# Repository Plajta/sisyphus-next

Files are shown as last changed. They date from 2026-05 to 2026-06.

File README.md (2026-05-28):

# Sisyphus
Sisyphus is an open-source, customizable soundboard. It's built to help folks who need assistive tech, but it's also great if you just want a cool device that makes noises when you hit buttons.

This repo contains everything you need to build one: the PCB designs, the 3D-printable case, and the firmware that makes it all work, with a construction manual in the works.

If you're looking for the web configurator to manage your sounds, check out [Lithos](https://lithos.plajta.eu/) (source code [here](https://github.com/Plajta/lithos)).

## Key features
With **RP2040** as it's beating heart and a nice crisp **I2S DAC**, it can even do CD quality audio (if you're into that kinda thing).
All the audio is kept in the device's **internal flash** held together by LittleFS making it resilient.

Made with our custom **[Eternity](https://github.com/Plajta/eternity) bootloader** it can be updated even from a browser. 

A built in **color sensor** makes it easy to swap your sound sets by just swapping in a piece of paper and **magnets** make it all feel like magic.
Built in a sturdy, slim, and light **3D-printed body**, held together by friction and screws for easy repairs. (Construction manual coming soon™)

## Directory structure
- [3D/](3D/) - The mechanical parts. Contains the FreeCAD project and [STLs](3D/STLs) ready for printing.
- [PCBs/](PCBs/) - KiCAD projects for the [mainboard](PCBs/sisyphus) and our own slim [RGB sensor module](PCBs/rgb_sensor).
- [src/](src/) - The firmware. It handles everything from the USB stack and keyboard matrix to the audio playback. Check its [README](src/README.md) for more details.

## Licensing
We take open-source seriously, so each part of the project has its own license to keep it fair:
- **3D & PCBs:** [CC-BY-SA](https://creativecommons.org/licenses/by-sa/4.0/)
- **Firmware (src):** [GPLv3](https://www.gnu.org/licenses/gpl-3.0.html)

That means you're free to use, modify, and even sell this—as long as you share your changes back with the community under the same terms.

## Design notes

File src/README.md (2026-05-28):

# Sisyphus Firmware
An RP2040 firmware built primarily for SisyFOSS boards. It includes a filesystem, color processing, a USB stack with a custom protocol, and a keyboard driver!

While this firmware is designed for custom boards, it can still run on a standard Raspberry Pi Pico, though the experience may be limited.

A custom linker script is used during the build process to reserve a dedicated section of the flash JUST for the LittleFS filesystem. This ensures that data is preserved when upgrading the firmware.

## Repository Structure
- [Audio](audio/) - Manages audio playback and loading - built from [RPi's code](https://github.com/raspberrypi/pico-playground/blob/master/audio/sine_wave/sine_wave.c)
- [Battery management](battery/) - Drivers for BMS chips
- [Boards](boards/) - Headers for supported boards
- [Color](color/) - Drivers for color sensors, color management, and color LUT
- [Eternity](https://github.com/Plajta/eternity) - Submodule for our custom 3rd-stage bootloader for the RP2040
- [Keyboard](keyboard/) - Drivers for keyboard controller ICs
- [LittleFS](https://github.com/littlefs-project/littlefs) - Submodule for an amazing and small fail-safe filesystem for microcontrollers.
- [Protocol](protocol/) - A custom protocol for file management, diagnostics, and configuration
- [USB](usb/) - TinyUSB configuration and descriptors
- [Util](util/) - Misc stuff, setup for LittleFS for the RP2040, ARGB LED color indicator

## Installation
To build the firmware from source, refer to the [Building](#building) section.

GitHub Actions automatically build the latest commits in three versions:
1. **Pico**: Standard firmware for the Raspberry Pi Pico (primarily for testing).
2. **Pico + Eternity**: Firmware for the Pico including the Eternity bootloader (also for testing).
3. **SisyFOSS**: Firmware for the SisyFOSS β board, including Eternity.

To install the standard Pico firmware, flash `sisyphus.uf2`.

Builds that include Eternity can be flashed in two ways:
1. Flash `combined.uf2` using the standard method.
2. If Eternity is already installed on the board, flash the `sisyphus.bin` file using the [web interface](https://lithos.plajta.eu/) (still WIP) or the [Eternity flasher](https://github.com/Plajta/eternity/blob/main/protocol/flasher.py).

## Usage
The primary way to interact with the firmware is through the [web interface](https://lithos.plajta.eu/) ([code](https://github.com/Plajta/lithos)).

If you want to take a look inside or just like to do stuff yourself, look inside in the [Protocol](protocol/) directory for its README and a bunch of interesting scripts.

To manually insert audio files, you also need to understand how the device chooses which file to play.
When a button is pressed, the firmware tries to play a file from its filesystem based on the following name template:
```
<color>_<row>_<column>.wav
```
- `<color>` - An ASCII letter mapped from the color LUT. See the [color](color/) directory for details.
- `<row>` and `<column>` - The coordinates of the button in the keyboard matrix (starting from 0).

### Initial Device Setup
When setting up a new or reset device with an empty filesystem, a few files must be prepared.

#### Color Lookup Table (LUT)
The LUT maps sensor readings to specific color codes and LED displays. To generate a stable LUT, run the [calibrator.py](protocol/calibrator.py) script with the device connected. The script will guide you through the calibration process using color samples, make sure to prepare those from the printer you plan on using in all the supported colors.

Currently supported colors:
- Red
- Green
- Blue
- Cyan
- Magenta
- Yellow
- White

For more information on color detection, see to the [color](color/) directory.

#### Volume Feedback Sample
An optional but recommended file, `volume_sample.wav`, provides audible feedback when the user adjusts the device volume. It should be a short chime representative of the volume of your typical audio samples.

The easiest way to prepare and upload this chime is using the [convert.py](protocol/convert.py) script:
```bash
python protocol/convert.py <path_to_audio_sample> volume_sample.wav
```
This script automatically converts the sample to 16-bit PCM at 22 kHz and uploads it to the device.

Alternatively, you can use a 3rd-party tool like Audacity to prepare the file and upload it via the [web interface](https://lithos.plajta.eu/) or the [shell.py](protocol/shell.py) script.

## Building
Building was only tested on Linux, it might work elsewhere but only to a limited extent.

If you are new to `pico-sdk` development, refer to the official Raspberry Pi documentation ([Getting Started](https://datasheets.raspberrypi.com/pico/getting-started-with-pico.pdf), [SDK Quick Start](https://www.raspberrypi.com/documentation/microcontrollers/c_sdk.html#quick-start-your-own-project)) for toolchain installation instructions.

1. **Update Submodules**: Ensure all submodules (Eternity and LittleFS) are cloned and up to date.
   ```bash
   git submodule update --init --recursive
   ```

2. **Create Build Directory**:
   ```bash
   mkdir build
   cd build
   ```

3. **Configure and Build**:
   Since the firmware is optimized for SisyFOSS boards, you should specify the board type. To include Eternity, use the `USE_ETERNITY` flag.
   ```bash
   cmake -DPICO_BOARD=plajta_sisyfoss_beta -DUSE_ETERNITY=ON ..
   make
   ```
   This should produce a bunch of binaries, but the ones you are interested in are either `sisyphus.uf2` (standard) or `combined.uf2` and `sisyphus.bin` (for Eternity-based systems). See the [Installation](#installation) section for deployment details.

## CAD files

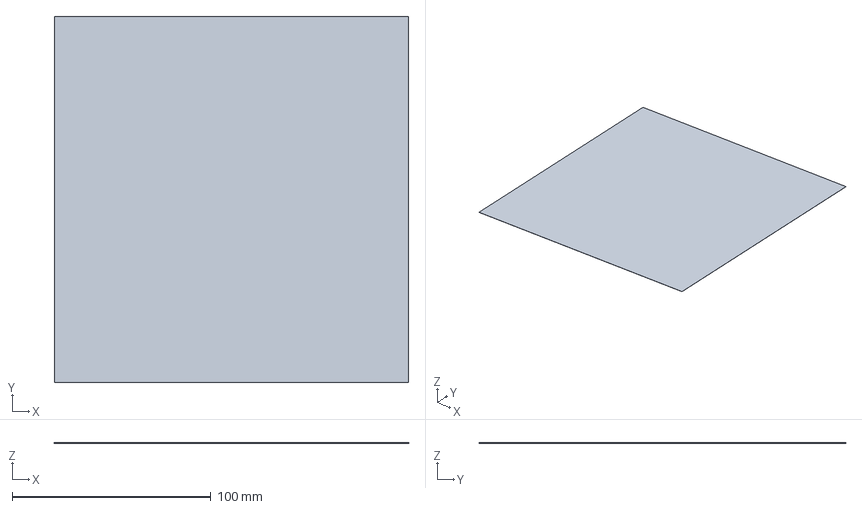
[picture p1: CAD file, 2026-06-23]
3D/Sisyphus.FCStd
178.0 x 184.0 x 0.1 mm

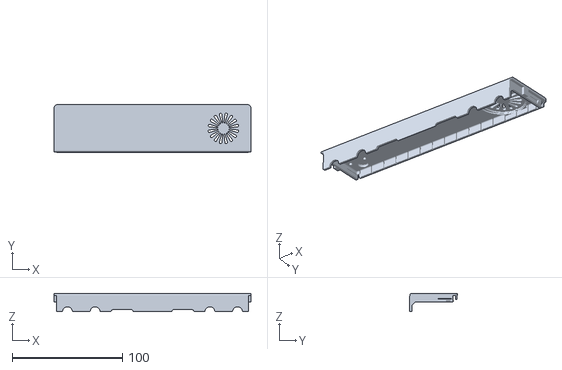
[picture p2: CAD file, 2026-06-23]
3D/STLs/TopCover-topcover.stl
178.4 x 43.4 x 16.6

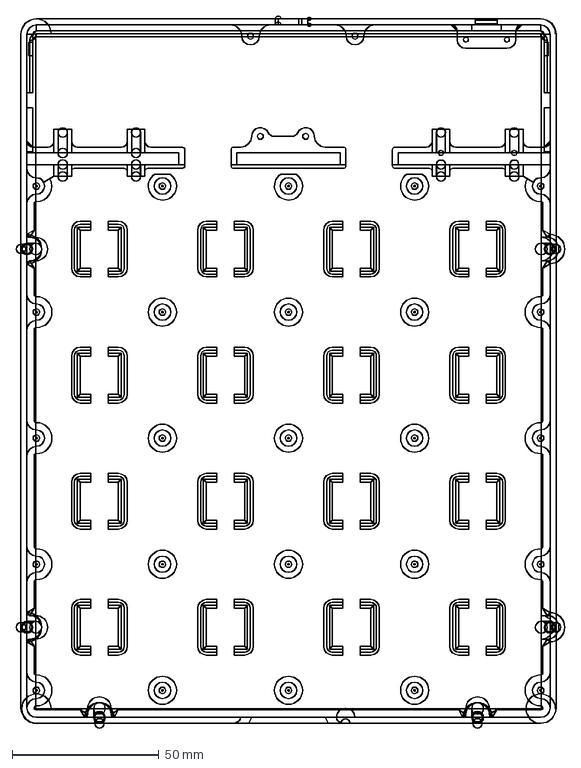
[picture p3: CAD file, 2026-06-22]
3D/STLs/Bottom-botom.dxf
187.0 x 242.8 mm

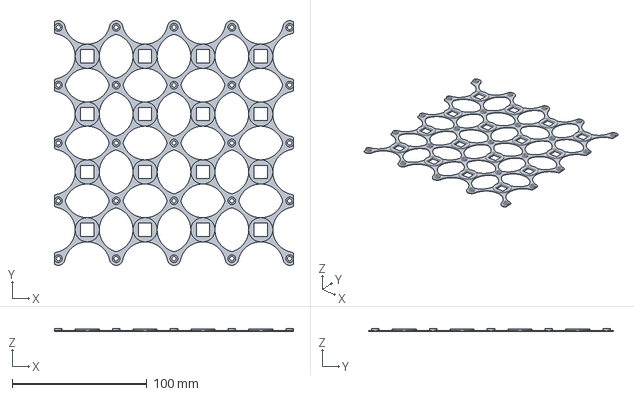
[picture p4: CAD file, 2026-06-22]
3D/Spring.FCStd
177.7 x 182.0 x 2.50 mm

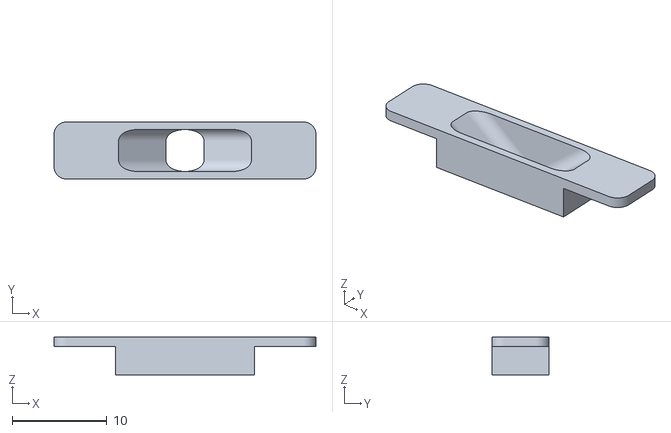
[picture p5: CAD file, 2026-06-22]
3D/STLs/Top-sensorcover.stl
27.6 x 6.00 x 4.00

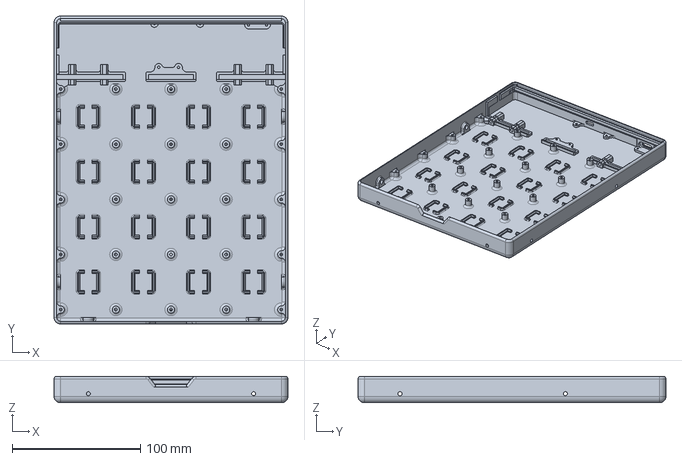
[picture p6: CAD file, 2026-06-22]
3D/Bottom.FCStd
182.5 x 240.2 x 20.6 mm

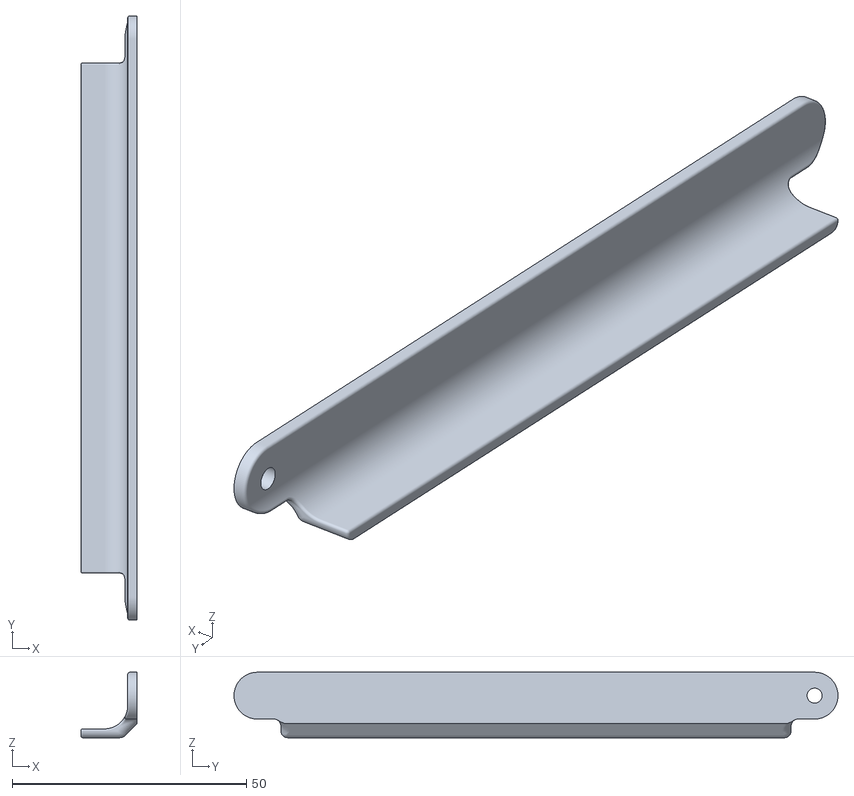
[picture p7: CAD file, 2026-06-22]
3D/STLs/sisyphus-leg.stl
12.0 x 129.0 x 14.0

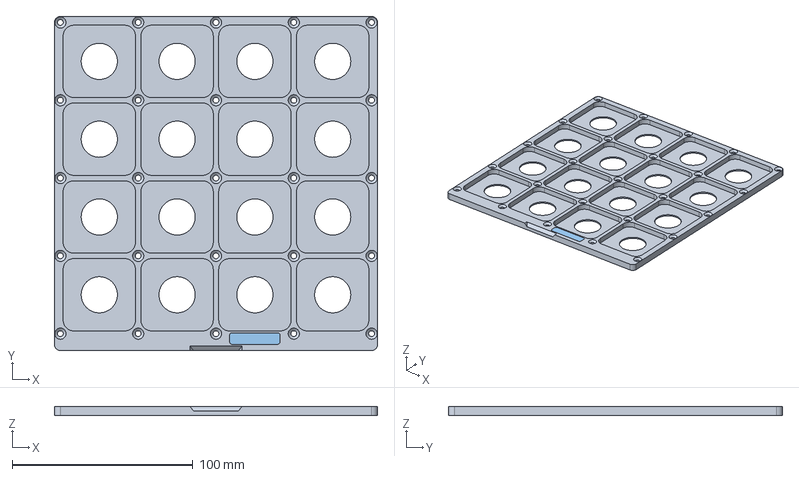
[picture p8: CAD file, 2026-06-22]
3D/Top.FCStd
178.6 x 184.6 x 5.00 mm
top
sensorcover
sensorglass

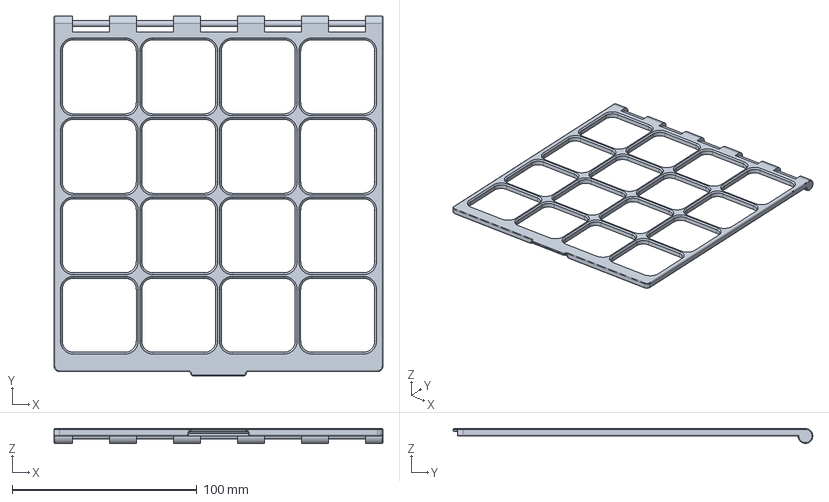
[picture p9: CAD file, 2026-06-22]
3D/Lid.FCStd
178.0 x 194.5 x 8.00 mm

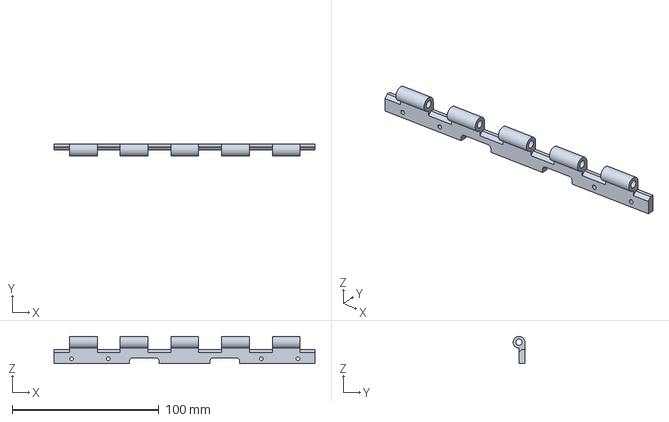
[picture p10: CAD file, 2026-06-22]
3D/Hinge.FCStd
178.0 x 8.00 x 18.6 mm

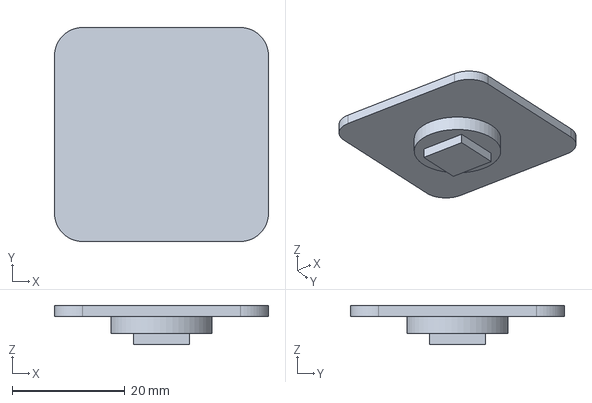
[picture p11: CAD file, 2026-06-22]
3D/KeyCap.FCStd
38.0 x 38.0 x 7.00 mm

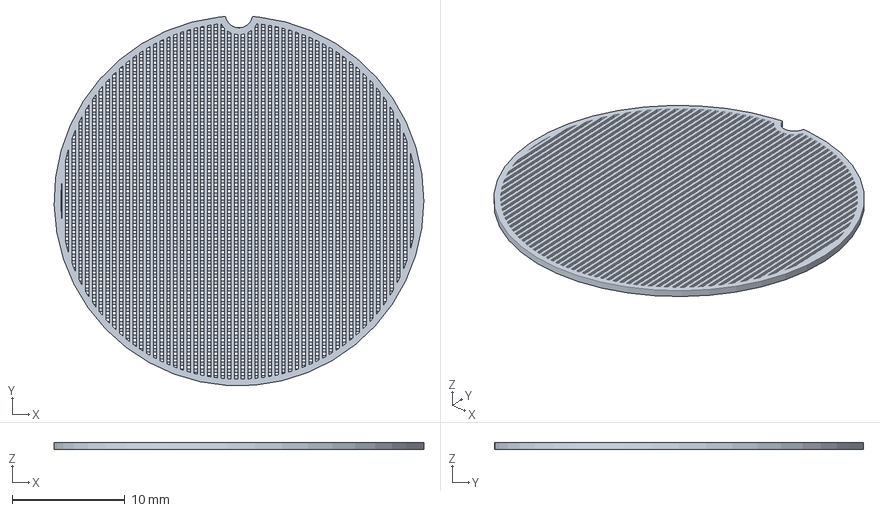
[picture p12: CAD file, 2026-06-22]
3D/Grille.FCStd
32.8 x 32.7 x 0.6 mm

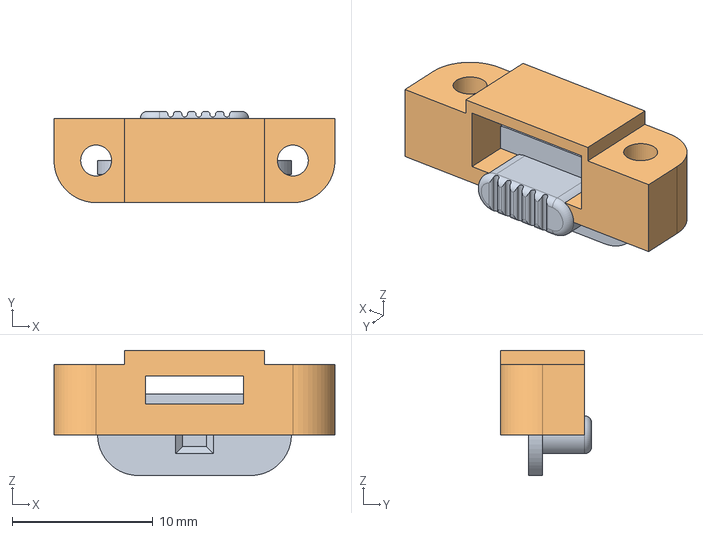
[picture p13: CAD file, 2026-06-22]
3D/Switch.FCStd
20.0 x 6.50 x 8.90 mm
switch
switchholder

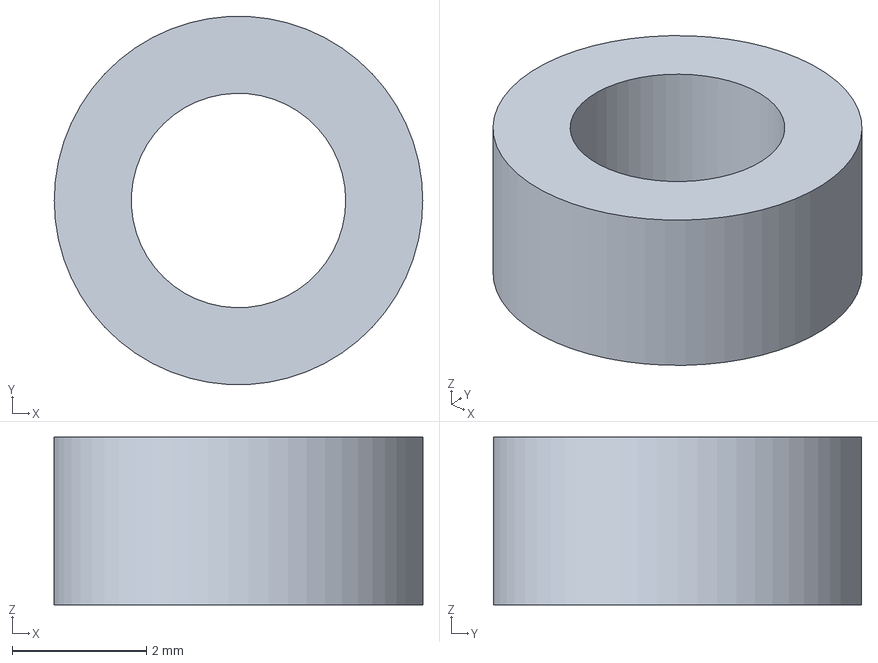
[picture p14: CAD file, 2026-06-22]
3D/BoardSpacer.FCStd
5.50 x 5.49 x 2.50 mm

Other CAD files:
3D/TopCover.FCStd
3D/Leg.FCStd
3D/STLs/Top.stl

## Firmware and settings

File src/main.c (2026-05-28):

#include <hardware/gpio.h>
#include <pico/error.h>
#include <pico/time.h>
#include <stdbool.h>
#include <stdio.h>
#include <bsp/board_api.h>
#include "class/cdc/cdc_device.h"
#include "pico/binary_info.h" // IWYU pragma: keep
#include <tusb.h>
#include "protocol.h"
#include "hardware/i2c.h"
#include "audio.h"
#include "color.h"
#include "ws2812.h"
#include "lightshow.h"

#ifdef SISYFOSS_HAS_KEYBOARD_CONTROLLER
#include "tca8418.h"
#endif

#ifdef SISYFOSS_COLOR_VEML3328
#include "veml3328.h"
#endif

#ifdef SISYFOSS_HAS_CHARGER
#include "bq25619.h"
#endif

#include "littlefs-pico.h"

#ifndef BUTTON_PIN
#define BUTTON_PIN 14
#endif

#ifdef SISYFOSS_I2S_ENABLE
bi_decl(bi_1pin_with_name(SISYFOSS_I2S_ENABLE, "I2S ENABLE"));
#endif

#if !defined(i2c_default) || !defined(PICO_DEFAULT_I2C_SDA_PIN) || !defined(PICO_DEFAULT_I2C_SCL_PIN)
#error Sisyphus requires a board with I2C pins
#endif

lfs_t lfs;

volatile bool wakeup = false;
volatile uint8_t button_index = 0;
#ifdef SISYFOSS_LID_DETECT
volatile bool lid_closed = false;
#endif

volatile bool trigger_volume_sample = false;
volatile bool trigger_color_scan = false;
volatile bool trigger_audio = false;

static repeating_timer_t usb_timer;

struct color_matched_entry matched_color;
bool matched_color_valid = false;
uint8_t audio_gain_shift_index = 0; // Should be clamped to ~6, indicates right shift of gain
#define AUDIO_GAIN_SHIFT_INDEX_MAX 6

i2c_inst_t *sisyfoss_i2c_inst = i2c_default;

static bool usb_background_task(repeating_timer_t *rt) {
    (void) rt;
    tud_task();  // TinyUSB background task
    return true; // Keep repeating
}

void light_fade_helper(uint32_t base_color){
    static lightshow_quartic_fade_state_t lightshow_state;

    lightshow_state.t = 0;
    lightshow_state.duration = 0.5;
    lightshow_state.reverse = false;
    lightshow_state.start_next_reversed = true;
    lightshow_state.base_color = base_color;

    lightshow_fade_setup(&lightshow_state);
}

// Taken out so we can call it before loop and on trigger
void scan_color(){
    color_measurement color;
    color_read_sensor(&color);
    // 170 is measured specifically for Sisyfoss's experimental 3D model right now, should be treated as a test number
    matched_color_valid = (color_lut_get_entry(&color, &matched_color, 100, 170) == PICO_OK);

    #ifdef PICO_DEFAULT_WS2812_PIN
    if (matched_color_valid)
        light_fade_helper(matched_color.led_color_representation);
    #endif
}

static void color_preset_helper(uint8_t index){
    struct color_entry* color_index;
    color_index = get_color_lut_entry(index);

    if (color_index == NULL){
        matched_color_valid = false;
        return;
    }

    matched_color.name = color_index->color_name;
    matched_color.led_color_representation = color_index->led_color_representation;
    matched_color_valid = true;
    light_fade_helper(matched_color.led_color_representation);
}

#ifdef SISYFOSS_HAS_KEYBOARD_CONTROLLER
void keyboard_interrupt() {
    if(!tca8418_k_int_available(sisyfoss_i2c_inst)){
        return;
    }

    uint8_t kbd_events = tca8418_num_events(sisyfoss_i2c_inst);

    // Re-check INT_STAT here (important per documentation)
    if (!tca8418_k_int_available(sisyfoss_i2c_inst)) {
        return;
    }

    uint8_t value;
    bool pressed;

    while (tca8418_num_events(sisyfoss_i2c_inst) > 0) {
        tca8418_get_key_from_fifo(sisyfoss_i2c_inst, &value, &pressed);
        if (pressed && !tud_cdc_connected()) {
            #ifdef SISYFOSS_LID_DETECT
            if (lid_closed){
                button_index = value;
                wakeup = true;
                trigger_audio = true;
            }
            else { // Settings mode
                switch (value){
                    case 11: // Volume down
                        if (audio_gain_shift_index < AUDIO_GAIN_SHIFT_INDEX_MAX)
                            audio_gain_shift_index++;
                        trigger_volume_sample = true;
                        wakeup = true;
                        break;
                    case 1: // Volume up
                        if (audio_gain_shift_index > 0)
                            audio_gain_shift_index--;
                        trigger_volume_sample = true;
                        wakeup = true;
                        break;
                    case 21: // First row of color table
                        color_preset_helper(0);
                        break;
                    case 22:
                        color_preset_helper(1);
                        break;
                    case 23:
                        color_preset_helper(2);
                        break;
                    case 24:
                        color_preset_helper(3);
                        break;
                    case 31:
                        color_preset_helper(4);
                        break;
                    case 32:
                        color_preset_helper(5);
                        break;
                    case 33:
                        color_preset_helper(6);
                        break;
                    case 34: // Last row of color table
                        color_preset_helper(7);
                        break;
                    default:
                        break;
                }
            }
            #else
            button_index = value;
            wakeup = true;
            trigger_audio = true;
            #endif
        }
    }

    // Clear the KE_INT interrupt bit by writing 1
    tca8418_k_int_reset(sisyfoss_i2c_inst);
}
#endif

void gpio_irq_dispatcher(uint gpio, uint32_t events){
    #ifdef SISYFOSS_LID_DETECT
    if (gpio == SISYFOSS_LID_DETECT && (events & GPIO_IRQ_EDGE_FALL)) {
        if (!matched_color_valid){
            wakeup = true;
            trigger_color_scan = true;
        }
        lid_closed = true;
    }
    else if (gpio == SISYFOSS_LID_DETECT && (events & GPIO_IRQ_EDGE_RISE)) {
        matched_color_valid = false;
        lid_closed = false;
    }
    #endif
    #ifndef SISYFOSS_HAS_KEYBOARD_CONTROLLER
    if (gpio == BUTTON_PIN && (events & GPIO_IRQ_EDGE_FALL)) {
        if(!tud_cdc_connected()){
            wakeup = true;
            button_index = 0;
            trigger_audio = true;
        }
    }
    #else
    if (gpio == SISYFOSS_KEYBOARD_INTERRUPT && (events & GPIO_IRQ_EDGE_FALL)) {
        keyboard_interrupt();
    }
    #endif
}

int main() {
    int err;
    #ifdef PICO_DEFAULT_WS2812_PIN
    // First of all get the status LED, so errors can be shown
    err = ws2812_init(PICO_DEFAULT_WS2812_PIN);
    hard_assert(err);
    #endif

    i2c_init(sisyfoss_i2c_inst, 100 * 1000);
    gpio_set_function(PICO_DEFAULT_I2C_SDA_PIN, GPIO_FUNC_I2C);
    gpio_set_function(PICO_DEFAULT_I2C_SCL_PIN, GPIO_FUNC_I2C);
    gpio_pull_up(PICO_DEFAULT_I2C_SDA_PIN);
    gpio_pull_up(PICO_DEFAULT_I2C_SCL_PIN);
    bi_decl(bi_2pins_with_func(PICO_DEFAULT_I2C_SDA_PIN, PICO_DEFAULT_I2C_SCL_PIN, GPIO_FUNC_I2C));

    #ifdef SISYFOSS_HAS_CHARGER
    bq25619_init(sisyfoss_i2c_inst); // init charger before all due safety reasons
    #endif

    tusb_init();
    // Run tud_task every millisecond just like pico_stdio would do
    add_repeating_timer_ms(1, usb_background_task, NULL, &usb_timer);

    #ifdef SISYFOSS_I2S_ENABLE
    gpio_init(SISYFOSS_I2S_ENABLE);
    gpio_set_dir(SISYFOSS_I2S_ENABLE, GPIO_OUT);
    gpio_put(SISYFOSS_I2S_ENABLE, 1);
    #endif

    err = pico_lfs_init(&lfs);

    if (err) {
        sleep_ms(5000);
        return 0; // Todo add a color indicated error
    }

    init_audio();
    err = color_init();

    gpio_set_irq_callback(&gpio_irq_dispatcher);

    #ifndef SISYFOSS_HAS_KEYBOARD_CONTROLLER
    gpio_init(BUTTON_PIN);
    gpio_set_dir(BUTTON_PIN, GPIO_IN);
    gpio_pull_up(BUTTON_PIN);
    gpio_set_irq_enabled(BUTTON_PIN, GPIO_IRQ_EDGE_FALL, true);
    #else
    tca8418_init(sisyfoss_i2c_inst);
    tca8418_setup_keyboard(sisyfoss_i2c_inst, 0b1111, 0b1111);
    tca8418_setup_interrupt(&keyboard_interrupt);
    #endif

    #ifdef SISYFOSS_LID_DETECT
    gpio_init(SISYFOSS_LID_DETECT);
    gpio_set_dir(SISYFOSS_LID_DETECT, GPIO_IN);
    gpio_pull_up(SISYFOSS_LID_DETECT);
    gpio_set_irq_enabled(SISYFOSS_LID_DETECT, GPIO_IRQ_EDGE_FALL | GPIO_IRQ_EDGE_RISE, true);
    lid_closed = !gpio_get(SISYFOSS_LID_DETECT);
    #endif

    // Enable GPIO IRQs
    irq_set_enabled(IO_IRQ_BANK0, true);

    #ifdef SISYFOSS_LID_DETECT
    if (lid_closed)
        scan_color();
    #else
    scan_color();
    #endif


    while (true) {
        // Check for USB-CDC connection
        if (tud_cdc_connected()) {
            #ifdef SISYPHUS_DEBUG
            char buf[128];
            // Get the things you wanna debug here
            snprintf(buf, sizeof(buf), "DEBUG MODE ON, DO NOT SHIP!!!\r\n");
            tud_cdc_write_str(buf);
            tud_cdc_write_flush();
            snprintf(buf, sizeof(buf), "DEBUG DATA: \r\n"); //add your debug data here
            tud_cdc_write_str(buf);
            tud_cdc_write_flush();
            #endif
            protocol_loop();
        }

        // If not connected and no button pressed, go to sleep
        while (!tud_cdc_connected() && !wakeup) {
            __wfi(); // Low-power wait for interrupt
        }

        if (wakeup) {
            wakeup = false;

            if (trigger_volume_sample){
                trigger_volume_sample = false;

                // Brighness steps between volume levels; +1 so min volume still has light
                uint8_t component_brightness_step = (LIGHTSHOW_MAX_WHITE_COMPONENT_BRIGHTNESS / (AUDIO_GAIN_SHIFT_INDEX_MAX));
                uint8_t component_brightness = LIGHTSHOW_MAX_WHITE_COMPONENT_BRIGHTNESS - (component_brightness_step * audio_gain_shift_index);

                static lightshow_flash_state_t blink_state;

                blink_state.base_color = (component_brightness << 16) | (component_brightness << 8) | component_brightness;
                blink_state.duration = 500;

                lightshow_flash_setup(&blink_state);
                play_audio("volume_sample.wav", AUDIO_MAX_GAIN >> audio_gain_shift_index);
            }

            if (trigger_color_scan) {
                trigger_color_scan = false;
                scan_color();
            }

            if(trigger_audio){
                trigger_audio = false;
                if (matched_color_valid && button_index != 0){
                    char filename[16]; // 16 should be enough
                    uint8_t buttom_column = (button_index % 10)-1;
                    uint8_t button_row = button_index / 10;
                    snprintf(filename, sizeof(filename), "%c_%d_%d.wav", matched_color.name, button_row, buttom_column);
                    play_audio(filename, AUDIO_MAX_GAIN >> audio_gain_shift_index); // shift index is clamped
                }
            }
        }
    }


    return 0;
}

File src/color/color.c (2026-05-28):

#include "lfs.h"
#include <hardware/gpio.h>
#include <pico.h>
#include <math.h>
#include <pico/error.h>
#include <pico/time.h>
#include <stdio.h>
#include <ctype.h>
#include <error.h>
#include <limits.h>
#include "color.h"

#ifdef SISYFOSS_COLOR_VEML3328
#include "sensors/veml3328/veml3328.h"
extern i2c_inst_t *sisyfoss_i2c_inst;
#endif

extern lfs_t lfs;
struct color_match_array color_lut;

/*
 * Accepts normalized RGB values
 *
 * Based on standard RGB to HSV conversion formula (didn't think it's that simple)
 *
 * Inspired by: https://www.geeksforgeeks.org/dsa/program-change-rgb-color-model-hsv-color-model/
 */
void color_rgb_to_hsv(float r, float g, float b, color_measurement *output_hsv){
    float color_max = fmax(r, fmax(g, b));
    float color_min = fmin(r, fmin(g, b));
    float diff = color_max - color_min;

    // if equal it's evaluated as grayscale
    if (color_max == color_min){
        output_hsv->hue = 0;
    }

    // otherwise get hue based on dominant color
    else if (color_max == r)
        output_hsv->hue = fmod(60 * ((g - b) / diff) + 360, 360);
    else if (color_max == g)
        output_hsv->hue = fmod(60 * ((b - r) / diff) + 120, 360);
    else if (color_max == b)
        output_hsv->hue = fmod(60 * ((r - g) / diff) + 240, 360);

    // Black (also so it doesn't explode on 0 division)
    if (color_max == 0)
        output_hsv->saturation = 0;
    else
        output_hsv->saturation = (diff / color_max) * 100;

    // just brightness
    output_hsv->value = color_max * 100;
}

static bool parse_int(char **p, long min, long max, long *out, int base) {
    char *endptr;
    long val = strtol(*p, &endptr, base);
    if (endptr == *p || val < min || val > max) {
        return false;
    }
    *out = val;
    *p = endptr;
    return true;
}

int color_lut_load(){
    lfs_file_t lut_file;
    int8_t error;

    error = lfs_file_open(&lfs, &lut_file, "color_lookup_table", LFS_O_RDONLY);
    if (error != LFS_ERR_OK) return PICO_ERROR_NOT_FOUND;

    struct color_entry *color_entries = NULL;
    size_t color_count = 0;
    size_t color_capacity = 0;

    free(color_lut.data); // Just to be sure, there might have been something
    color_lut.data = NULL;
    color_lut.len = 0;

    char c;
    char buffer[MAX_LUT_LINE_SIZE];
    size_t i = 0;
    int ret;

    while (true) {
        ret = lfs_file_read(&lfs, &lut_file, &c, 1);

        // Break the loop if we're at the end of the file or there is an error
        if (ret < 1) {
            break;
        }

        // This line is too long
        if (i >= MAX_LUT_LINE_SIZE){
            i = 0;
            continue;
        }

        if (c != '\n') {
            buffer[i++] = c;
        }
        else {
            buffer[i] = '\0'; // End it with a NUL just to be sure
            char *p = buffer;
            char *endptr;

            // Get color values
            long hue_ul, sat_ul, val_ul;
            if (!parse_int(&p, 0, 360, &hue_ul, 10) ||
                !parse_int(&p, 0, 100, &sat_ul, 10) ||
                !parse_int(&p, 0, 100, &val_ul, 10)) {
                i = 0;
                continue; // Bad line
            }

            while ((p - buffer) < i && isspace((unsigned char)*p)) p++; // Skip whitespace, with safety

            // Get color code name
            char color_name = *p++;

            if (!isalpha((unsigned char)color_name)) {
                // Bad color code
                i = 0;
                continue;
            }

            while ((p - buffer) < i && isspace((unsigned char)*p)) p++; // Skip whitespace, with safety

            // Get color representation for LED
            long color_representation;
            if(!parse_int(&p, 0, 0xFFFFFF, &color_representation, 16)){
                color_representation = 0; // Not found default to 0
            }


            // Test memory capacity and add to table
            if (color_count == color_capacity){
                size_t new_capacity = color_capacity ? color_capacity * 2 : 2;
                struct color_entry *temp = realloc(color_entries, new_capacity * sizeof(struct color_entry));
                if (!temp) { // Probably out of memory :(
                    free(color_entries);
                    lfs_file_close(&lfs, &lut_file);
                    return PICO_ERROR_INSUFFICIENT_RESOURCES;
                }
                color_entries = temp;
                color_capacity = new_capacity;
            }

            struct color_entry *color = &color_entries[color_count++];
            color->hue = (uint16_t)hue_ul;
            color->saturation = (uint8_t)sat_ul;
            color->value = (uint8_t)val_ul;
            color->color_name = color_name;
            color->led_color_representation = color_representation;

            i = 0;
        }
    }
    lfs_file_close(&lfs, &lut_file);

    color_lut.data = color_entries;
    color_lut.len = color_count;

    // Successfully read
    return 0;
}

int color_init() {
    #ifdef SISYFOSS_AUX_SENSOR_LED
    gpio_init(SISYFOSS_AUX_SENSOR_LED);
    gpio_set_dir(SISYFOSS_AUX_SENSOR_LED, GPIO_OUT);
    gpio_put(SISYFOSS_AUX_SENSOR_LED, true);
    #endif

    // Does not immediately return because LUT can be missing and that would leave a part of the device unitialized
    int err = color_lut_load();

    #ifdef SISYFOSS_COLOR_VEML3328
    err = veml3328_setup(sisyfoss_i2c_inst);
    #endif

    return err;
}

int color_read_sensor(color_measurement *color) {

    #ifdef SISYFOSS_AUX_SENSOR_LED
    gpio_put(SISYFOSS_AUX_SENSOR_LED, false); // Turn the AUX LED ON
    #endif

    #ifdef SISYFOSS_COLOR_VEML3328
    veml3328_shutdown(sisyfoss_i2c_inst, false); // Wake the sensor
    veml3328_trigger(sisyfoss_i2c_inst);
    #endif

    #ifdef SISYFOSS_AUX_SENSOR_LED
    sleep_ms(150); // So the light has time to integrate
    #endif

    #ifdef SISYFOSS_COLOR_VEML3328
    veml3328_read_color(sisyfoss_i2c_inst, color);
    #endif

    #ifdef SISYFOSS_AUX_SENSOR_LED
    gpio_put(SISYFOSS_AUX_SENSOR_LED, true);
    #endif

    #ifdef SISYFOSS_COLOR_VEML3328
    veml3328_shutdown(sisyfoss_i2c_inst, true); // Sleep the sensor
    #endif

    return PICO_OK;
}

struct color_entry* get_color_lut_entry(uint8_t index){
    if (color_lut.data != NULL || index < color_lut.len) {
        return &color_lut.data[index];
    }
    return NULL;
}
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

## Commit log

2026-05-24 Change sample freq to 22000
    We really do not need CD quality LMAO. The small speakers don't stand a chance at reproducing that.
2026-05-24 Update README.md
    Add info about the audio filenames on the devices filesystem.
2026-05-24 Update maximum color distance
    Made the distance a little bit tighter, needs testing but seems to work nice and eliminates false positives
    [main.c]
2026-05-24 Add volume control
    Also add a variable to check if the lid is open or closed and used it in one place where it doesn't even need to be
    It might be a little bit fishy UX-wise tho, top left button (1) is volume - and the one to the right (2) is +
    [main.c]
2026-05-24 Change volume button layout
    Now first button in first row is + and first button is second row is -
2026-05-24 Rewrite CMakeLists so more boards actually work
    This rewrite does not include any additional boards, just the stuff to make any future one work
2026-05-24 Add a visual and sound feedback for volume control
    Visual feedback is provided by the onboard ARGB LED. The brighness values maybe better gathered from some kind of exponential function. Will have to look into that.
    Sound feedback is optionally provided by an onboard file named `volume_sample.wav` that gets played after the volume changes.
2026-05-28 Add a manual override for color picking
    Bottom two rows of buttons in settings mode (open lid) are used for overriding colors. When you press them, the 1st to 8th line of the LUT gets selected instead of the one on the paper.
    Add a light fade helper to main, used for color scanning and for indicating which color has been picked using the override.
    Implemented using an old function for debugging now normally available.
2026-06-22 Separated bodies and created assembly to improve FreeCad performance while modeling
    [BoardSpacer.FCStd, Bottom-botom.dxf, Bottom.FCStd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]
2026-06-23 Improved closing of electronics cover
    [Sisyphus.FCStd, TopCover-topcover.stl, TopCover.FCStd]
